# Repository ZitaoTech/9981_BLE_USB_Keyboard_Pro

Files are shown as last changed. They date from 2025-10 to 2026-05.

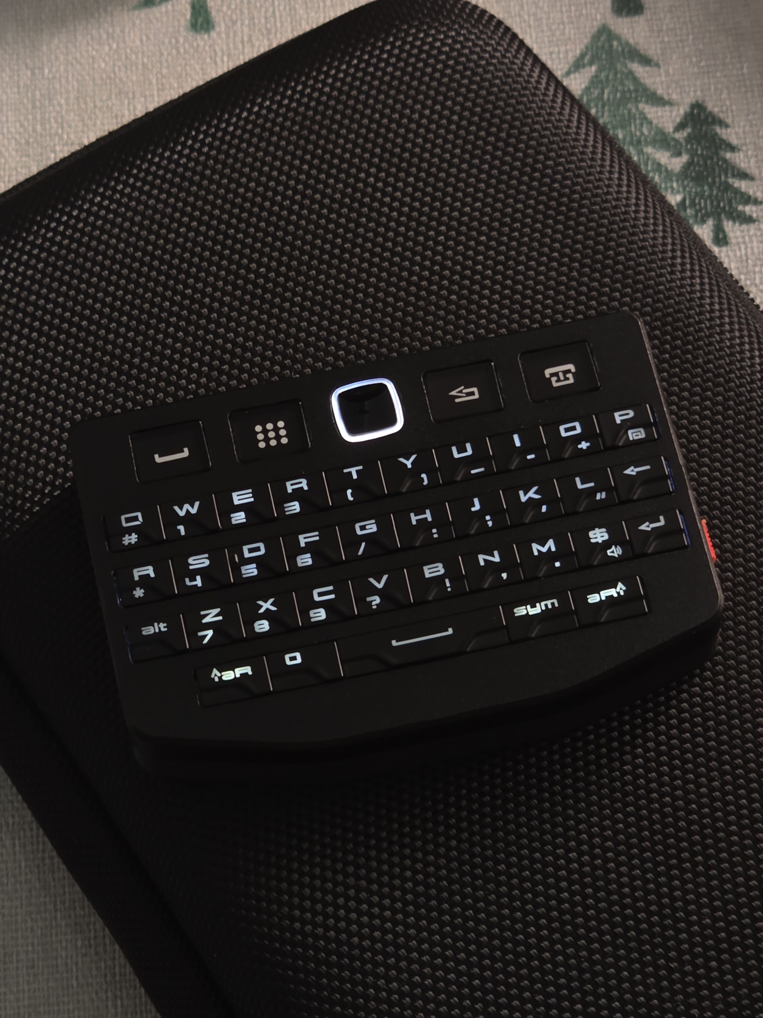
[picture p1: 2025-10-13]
Gallery/Foto2.jpg

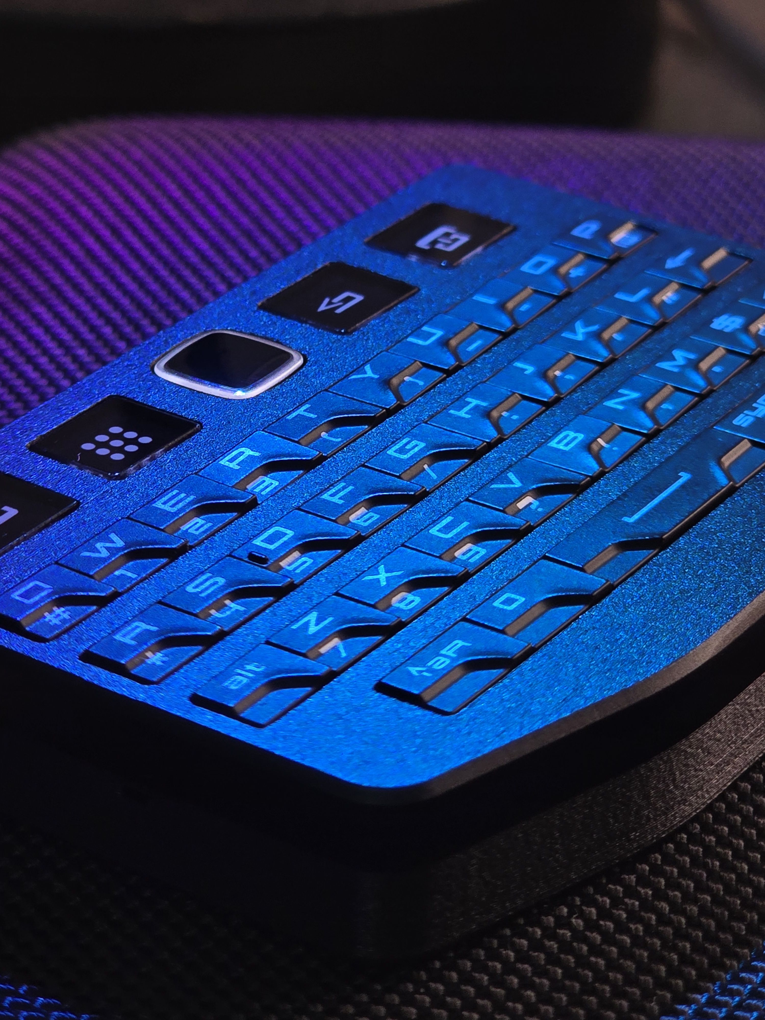
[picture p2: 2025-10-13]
Gallery/Foto5.jpg

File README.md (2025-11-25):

# P9981 BLE&USB Keyboard Pro ⌨️
The fully open-sourced P9981 BLE&USB Keyboard is the smallest ZMK-powered keyboard mouse combo and features n-Key rollover that other original blackberry keyboards don't have!

### [You might also be interested in P9981 Keyboard Air](https://github.com/ZitaoTech/9981_BLE_USB_Keyboard_Air/tree/main)
# Image Gallery

<table>
    <tr>
        <td></td>
        <td></td>
    </tr>

</table>

## Contents
- [About this keyboard](#about-this-keyboard-)
- [Before you buy/use](#before-you-buyuse-)
- [Where to buy](#where-to-buy-)
- [How to use this keyboard and keymap](#how-to-use-this-keyboard-)
- [How to connect this keyboard with your device](#how-to-connect-this-keyboard-with-your-device-)
- [Multi device connect](#multi-device-connect-)
- [Trackpad](#trackpad-)
- [USB&BLE Output select](#usbble-output-select-)
- [Keymap updating](#realtime-keymap-updating-)
- [Tipps for Android and iPhone users](#some-tipps-for-using-this-keyboard-)
- [Advanced methods of using this keyboard](#advanced-methods-of-using-this-keyboard-)
- [Troubleshoot](#troubleshoot-)
- [Dimension and weight](#dimensions-of-the-keyboard-)
- [Inspiration](#inspiration-)

# About this keyboard [🔼](#contents)
This mini Keyboard uses the cloned P9981 keycap with Blackberry 9380 trackpad and powered by the NRF52840 Microcontroller and operates under ZMK Firmware with extra custom driver.  

| Main Features |  | 
| :--- | :----: |
| Processor | [NRF52840](https://www.nordicsemi.com/products/nrf52840) from Nordic Semiconductor | 
| Firmware | ZMK firmware  | 
| Backlight | Keyboard with white backlight|
|Battery type| Integrated li-on battery|
|Battery capacity| 750mah with up to 3 months battery life(assume 1 hour per day)|
|Mouse and scroll wheel 2 in 1|When Capslock, the trackpad works as scroll wheel|
|USB&BLE Output|Support both wired and wireless connect|
|Shoulder keys|There are two shoulder keys on top|
|Small size| The smallest wireless keyboard mouse combo in the world|
|Aluminium body|The top case is made of aluminium, lower case 3d printed|
|Multidevice connect| The keyboard can be paired with up to 4 devices at the same time|
|Open source| [Hardware](https://github.com/ZitaoTech/9981_BLE_USB_Keyboard_Pro/tree/main/Hardware) and [software](https://github.com/ZitaoTech/9981_BLE_USB_Keyboard_Pro/tree/main/ZMK%20source%20code) all open sourced|
|__NKRO__|__There are integrated diodes on the keyboard, all the keys can be pressed at the same time__(Other original Blackberry keyboards don't have this feature)|

## Before you buy/use [🔼](#contents)

**Bluetooth version check**: This keyboard can only be paired wirelessly with devices that have **BLE 4.2 module or higher**, please check if your device have the right Bluetooth module, otherwise the keyboard can not work with your device wirelessly!  
How to check the Bluetooth version of your device: google (your device name) like iphone 8 and plus Bluetooth version and you will find the answer like this:
 BLE VERSION CHECK

## Where to buy [🔼](#contents)
- **If you are outside China**: You can buy the keyboard at [Elecrow](https://www.elecrow.com/p9981-ble-usb-keyboard-pro.html)    
- **If you are in China**: 在闲鱼搜索用户御坂200016号

# How to use this keyboard [🔼](#contents)
- By default the keyboard has 4 Layers, when you just turn on the keyboard, the keyboard is at layer0-the QWERTY layer.  
- When you tap or hold the ```SYM``` key, the keyboard will enter layer1, and the keyboard backlight will start blinking, you can type numbers or symbols at this layer.  
- When you tap or hold the ```aA``` key at the lower right corner, the keyboard will enter layer2 and the keyboard backlight will do a loop effect, you can type some symbols and do some Bluetooth behaviors at this layer.
- The layer 3 basically has no keycode, this layer is reserved for the customer, and the keyboard backlight will blink the twice speed as the layer 1 when you are at layer 3.  

**Now let's check the keymap.**  
## Keymap [🔼](#contents)
**Layer0-QWERTY**    
<p align="center">
  9981_PRO_layer0
</p>

> [!NOTE]
> - **What means sticky ctrl?** If you want to copy something, you can tap Ctrl and then tap C, the keyboard will triger Ctrl+C, you can do that with one hand.  
> - **What means sticky layer?** A sticky layer stays pressed until another key is pressed. Example: when you short type sym key, the keyboard will enter sticky layer1 after you type the "B" key, the keyboard will type "!" and return to layer0, it's easier to type with one hand.  
> - **What means lock layer?** The "lock layer" behavior enables a layer while a certain key is pressed. Example: when you want to type many numbers you can hold the sym key and tap "WER" and the keyboard will type "123", when you release the sym key, the keyboard will return to layer 0.  
> - **What means to layer?** By default when you double tap the dollar key, the keyboard will go to layer 1, then you can type numbers without pressing the sym key, you need to manually return to layer0 by tap the sym key at layer1.  

**Layer1-Numbers and symbols**    
<p align="center">
9981_PRO_layer1 
</p>
 
**Layer2-Functional keys**   
<p align="center">
9981_PRO_layer2  
</p>

> [!NOTE]
> - **What does Eject key do?** When you press E at layer 2, the keyboard will type Eject, Eject can ```bring up``` or ```disable``` keyboard on screen on iphone, this key is important because on iphone by default the keyboard on screen is disable when iphone is connected withe external keyboard.
> - Double tap the trackpad on this layer which trigger the ```Clear bluetooth pairing``` is very important to pair with another device more info please check the content [How to connect this keyboard with your device](How-to-connect-this-keyboard-with-your-device-)
> - This Layer contains many important keycode about Bluetooth connect and Multiconnect, more info please check

**Layer3-Reserved layer for extra keys**   
<p align="center">
9981_PRO_layer3 
</p>

> [!NOTE]
> - You enter Layer 3 by double tap dollar key at layer 1, you can customize how to enter this layer yourself by editting the keymap.  
> - You can set some key at this layer as Media key like ```next song``` or ```pause``` which I think should be useful.

## How to connect this keyboard with your device [🔼](#contents)
- Turn on the Bluetooth on your phone
- Find the device ```bbp9981``` and pair with it then you should type with the keyboard
- There are some settings for IOS users, please check [this](https://github.com/ZitaoTech/9981_BLE_USB_Keyboard_Pro/tree/main?tab=readme-ov-file#iphone-or-ios-users-).
> [!CAUTION]
> After you delete the bluetooth profile and if you want to pair with the keyboard with another device when you have already paired with some device before, make sure to enter layer 2 and double tap the trackpad to clear the bluetooth profile on the keyboard side. Otherwise there will be error when you want to pair with another device!!! Please use the following steps to delete the bluetooth pairing
- First delete the bluetooth profile(somewhere it's called forget the device or unpair the device) on your device
- Enter layer 2 and doubletap the trackpad(You can tap the lower right aA key to trigger sticky layer 2 or hold the aA key to enter layer2)
- Refresh the Bluetooth setting page on your device(You can turn on and off the bluetooth) and then you can pair with the keyboard again

## Multi device connect [🔼](#contents)
By default the keyboard can be paired with 4 devices at the same time and can be switched between them seamlessly. Here are the steps how to connect with devices:
1. Assume you have already connected this keyboard with one device
2. Now enter layer 2 and press the second bigger top row key
<p align="center">

</p>
Now the keyboard is ready to be paired with second device.  
Similarly, you can pair this keyboard with a third and a fourth device.  

3. Once pairing is done, you can switch between the devices the same way.

> [!CAUTION]
> - The BT_CLEAR keycoode — which is triggered by double-tapping the trackpad on Layer 2 — is calculated independently for each device. This means that when you trigger BT_CLEAR while connected to the second device, it won’t affect any of the other devices.

## Trackpad [🔼](#contents)
- There is a trackpad which can be used as mouse, iPhone users need to enable the AssistiveTouch function to use the trackpad as mouse.  
- Trackpad led: When you put your finger on the trackpad, the trackpad led will light up and the brightness will show the speed of the mouse speed(the higher the dpi, the more brighter the led) When the keyboard is waiting to be paired or the output is USB, the trackpad led will start blinking.  
- How to adjust the mouse speed: Enter layer 2 and press V to decrease the dpi, or press N to increase the dpi. The dpi can be shown by the brightness of the trackpad led.
- Scroll function: When Caps Lock is activated, the trackpad led enters a cyclic lighting mode, and the trackpad works as a scroll wheel.

## USB&BLE Output select [🔼](#contents)
The keyboard supports both USB and BLE output, by default the output is BLE. Assume the keyboard is both connected with a PC and paired with a phone, you can toggle the output by double-tapping the dollar key at layer2, if the output is USB the trackpad led will start blinking every second.

## Realtime Keymap Updating [🔼](#contents)
[ZMK Studio](https://zmk.dev/docs/features/studio) provides runtime update functionality to ZMK powered devices, allowing users to change their keymap layers without flashing new firmware to their keyboards.  

You can use ZMK Studio with ```Chrome/Edge``` at [https://zmk.studio/](https://zmk.studio/).  

Before you use ZMK Studio, you need to ```turn off``` the bluetooth from your phone that the keyboard is paired with, then you can select the port shown on the ZMK Studio page and then start the keymap updating.  

The picture below shows you how it looks like when the keyboard connects with ZMK Studio successfully.

<p align="center">

</p>

> [!NOTE]
> Currently The ZMK Studio is still beta version, there are some functions that ```can not``` be configured e.g. macro, 
> there is another advanced way to update the keymap, please check the content below

## Advanced Keymap Updating [🔼](#contents)
Since the ZMK Studio is still in beta stage, There’s also a more straightforward method to edit the keymap.  
Please refer to this [page](https://github.com/ZitaoTech/zmk-config-9981-pro)

## How to update the firmware [🔼](#contents)
Because this keyboard is powered by open sourced ZMK firmware, which allows you to modify different features yourself, and thus you might need to update the firmware yourself. The following are steps to update the firmware.

1. Connect the keyboard with a computer
2. Make the keyboard into bootloader mode(By default you need to enter layer2 and press the dollar key)
3. A new USB Disk will be found by you computer
4. Drag the new .uf2 firmware file into the USB Disk and the keyboard is finished with updating

## Emergency way to enter bootloader [🔼](#contents)
There is a hole at the bottom of the keyboard, and inside that's the reset button. After connect the keyboard with a computer, you can quickly tap the reset button using a small pin to force the keyboard into ```bootloader mode```

<p align="center">

</p>

# Some tipps for using this keyboard [🔼](#contents)
## iPhone or IOS users [🔼](#contents)
If you need to use trackpad as mouse or scroll wheel function on iphone or ipad, there are some settings that you need to do:

- Go to Settings-> Accessibility-> Touch-> AssistiveTouch -> enable AssistiveTouch and you can use touchpad as mouse on iphone or ipad
- Go to Settings-> General-> Keyboard-> Hardware Keyboard-> disable Cpas Lock Language Switch and you can use the trackpad as scroll wheel when capslock is on.

And you can disable the always show menu to remove the grey dot when your phone is connected with keyboard
<p align="center">

</p>

## Android users [🔼](#contents)
I noticed that about ten seconds after the keyboard is paired with an Android phone for the first time, it will reconnect once. During this brief period, you won’t be able to type or move the mouse. This is normal, so don’t worry.

Shortcuts: 
**There are some useful shortcuts on android phones:**
- Hold gui key and press N to check messages.
- Hold gui key and press enter to go to desktop.
- Hold alt and press tab to enter multiapp control.

**What's the ```gui key```?**
<p align="center">

</p>
By default that's the second bigger top row key, it's also the command key(⌘) on IOS

# Advanced methods of using this keyboard [🔼](#contents) 

## Build your own firmware [🔼](#contents)
First you need to build the toolchain of ZMK firmware, it's recommended to build it under Github Codespaces. Here are the steps for you to build the toolchain via Codespaces:  
0. Register a Github account if you don't have one
1. Access the zmk firmware [github page](https://github.com/zmkfirmware/zmk)  
2. Create a codespace by clicking this icon:

<p align="center">

 </p>
 
3. When the codespace is finished setting up, type ```cd zmk ``` in the terminal of the codespace
4. type ```west init -l app/``` in the terminal
5. type ```west update``` and wait about 5-10 minutes and the toolchain is finished setting up
6. copy and paste the ```bbp9981``` [folder](https://github.com/ZitaoTech/9981_BLE_USB_Keyboard_Pro/tree/main/ZMK%20source%20code/bbp9981) into the ```app/boards/arm``` folder
7. compile the firmware by using ```cd app``` and ```west build -p -b bbp9981``` and zmk will start compiling the firmware
8. the compiled firmware is ```app/build/zephyr/zmk.uf2```. You can download and update the firmware
# Troubleshoot [🔼](#contents)
- Why did the keyboard feel bad to type on when I first receive it?

Because the keycap is made of silicone, when the keyboard is transported by air, the low temperature can make the silicone stiffen slightly. So when you first receive the keyboard, it may feel bad to type with. Once it warms up to room temperature, the typing feel will improve. The same thing also happens with other BlackBerry keyboards.  
- Why is my trackpad not moving?

The trackpad can be manually turned on/off. You may have accidentally pressed ‘T’ on Layer 2 and disabled it. In this case, enter Layer 2 again and press ‘T’ once more to re-enable the touchpad.  

There is another possibility: the trackpad itself might be defect. Here is a quick way to verify it:  

First, place your finger on the touchpad and move. See whether the trackpad backlight lights up.
If not, enter Layer 2 and press ‘T’. Then place your finger on the trackpad again and move.
If the trackpad backlight still does not light up, the touchpad is likely defective.
In this case, please contact Elecrow.  

- Why can't my keyboard be paired with my device?

It’s possible that after the previous pairing, the keyboard didn’t clear its pairing information. You need to switch to Layer 2 and double-tap the touchpad to erase the keyboard’s pairing data, and then you can start a new pairing.

> [!CAUTION]
> After deleting the pairing on your phone or on the keyboard, it’s important to refresh the Bluetooth page on your device. The easiest way is to just restart Bluetooth module.

If in this way your device still can't pair with the keyboard, please follow the steps below:  

Press and hold the **aA** key at the bottom-right corner, then press the **first top-row key**, and double-tap the touchpad.  

Next, without releasing the aA key, press the **second top-row key**, and double-tap the touchpad again.
Repeat this process for **all four top-row keys** to clear pairing information for all 4 bluetooth channels.  

After that, pair your device with the keyboard again.

- Why is my keyboard not having backlight?

Enter layer 2 and press ‘B’ so you can bring the backlight back again

# Others [🔼](#contents) 
## Dimensions of the keyboard [🔼](#contents)
The picture below shows the outerline dimension of the keyboard  
9981_PRO_dimension
## Weight [🔼](#contents)
The total weight of the keyboard is 53.3 g

# Inspiration [🔼](#contents) 
This [page](https://github.com/ZitaoTech/9981_BLE_USB_Keyboard_Pro/tree/main/Inspiration) shows what the keyboard can do besides functioning as a standalone Bluetooth keyboard.

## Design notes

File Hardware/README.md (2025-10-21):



There are two custom PCBs inside the keyboard:  
1. Dome sheet PCB with 1.6mm thickness  
2. Main PCB with 1.0mm thickness  

These two PCBs are connected via two 16-pin board-to-board connectors

Dome sheet PCB:  
3fd71eb90a61267e5f55e46590c34631
There will be a custom ordered dome sheet attached on the PCB  
5c5008502b5ae1ba0b157d0c470c3f69
Foto of the two PCBS:  
0297fbe53108b78d6377a41427420c7a

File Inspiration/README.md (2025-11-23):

# Inspiration
This page shows what the keyboard can do besides functioning as a standalone Bluetooth keyboard.

- ### Connect with a phone with magnet system
<div style="display: flex; gap: 10px;">
  
  
</div>

- ### Mini cyberdeck
<p align="center">

</p>

- ### Custom enclosure
<p align="center">

</p>

- ### Phone case for Samsung Z Flip 5 or 6
<p align="center">

</p>

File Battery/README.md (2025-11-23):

# Battery inside the 9981 BLE&USB keyboard

The battery used on 9981 pro keyboard is ```503048``` 750mah Lithium-ion battery.

All certifications and documents related to this battery are in the folder on this page

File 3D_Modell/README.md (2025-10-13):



Screws needed to assemble 9981 BLE&USB keyboard pro:  

4 pcs ```M2x10``` hexagon socket countersunk head screws  
2 pcs ```M2x4``` flat head countersunk head screws

### Parameter about the 3d printed part:

Print maschine: Bambu Lab A1 mini    
```Red switch:``` Nozzel size:0.2mm  
```Top Row key support:``` Nozzel size:0.2mm  
```Lower case:``` Nozzel size:0.4mm

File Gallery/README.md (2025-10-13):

Foto1
Foto2
Foto3
Foto4
Foto5
Foto6
Foto7

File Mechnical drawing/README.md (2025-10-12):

9981_PRO_dimension

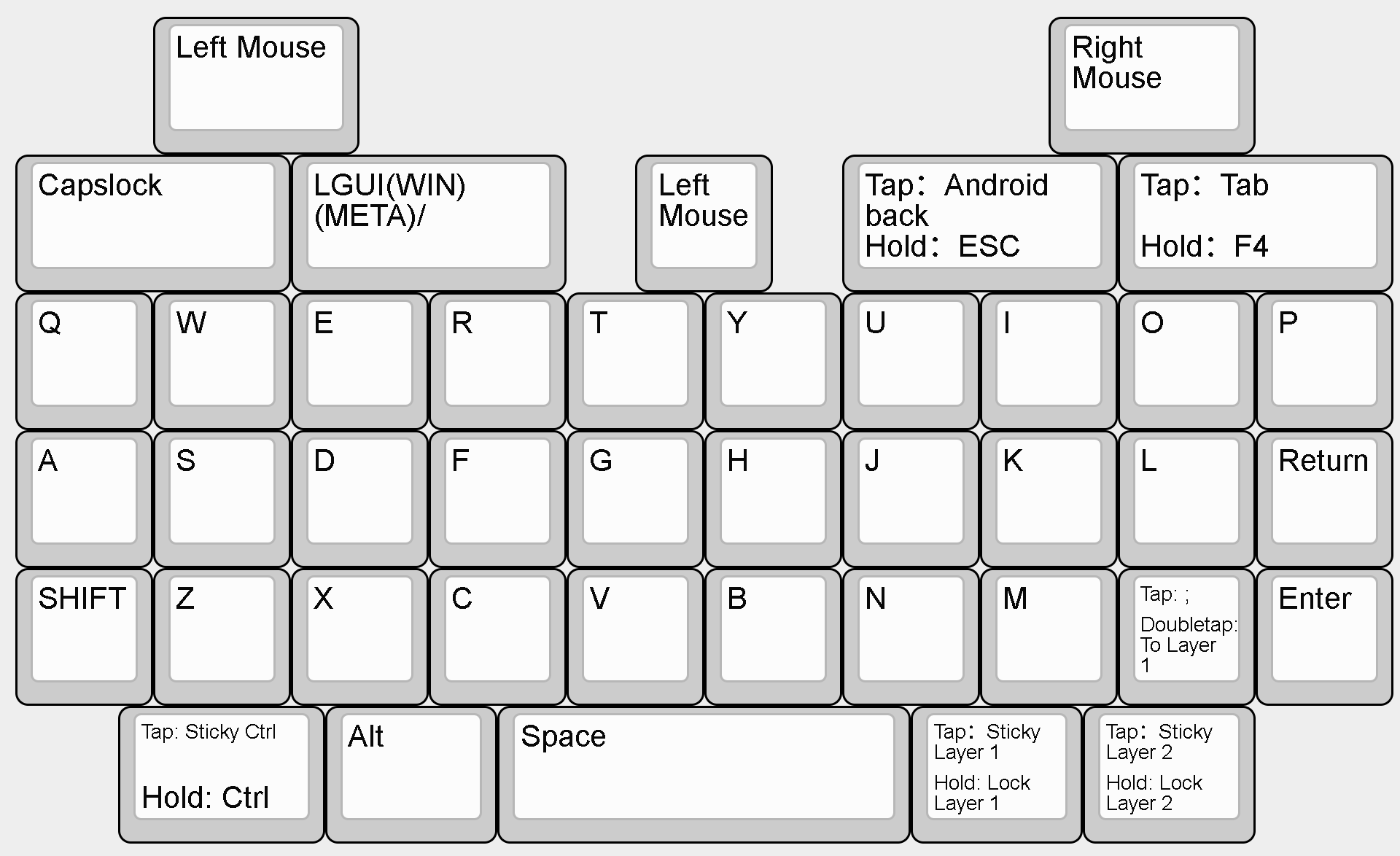
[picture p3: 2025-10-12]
Pic/9981_PRO_layer0.png

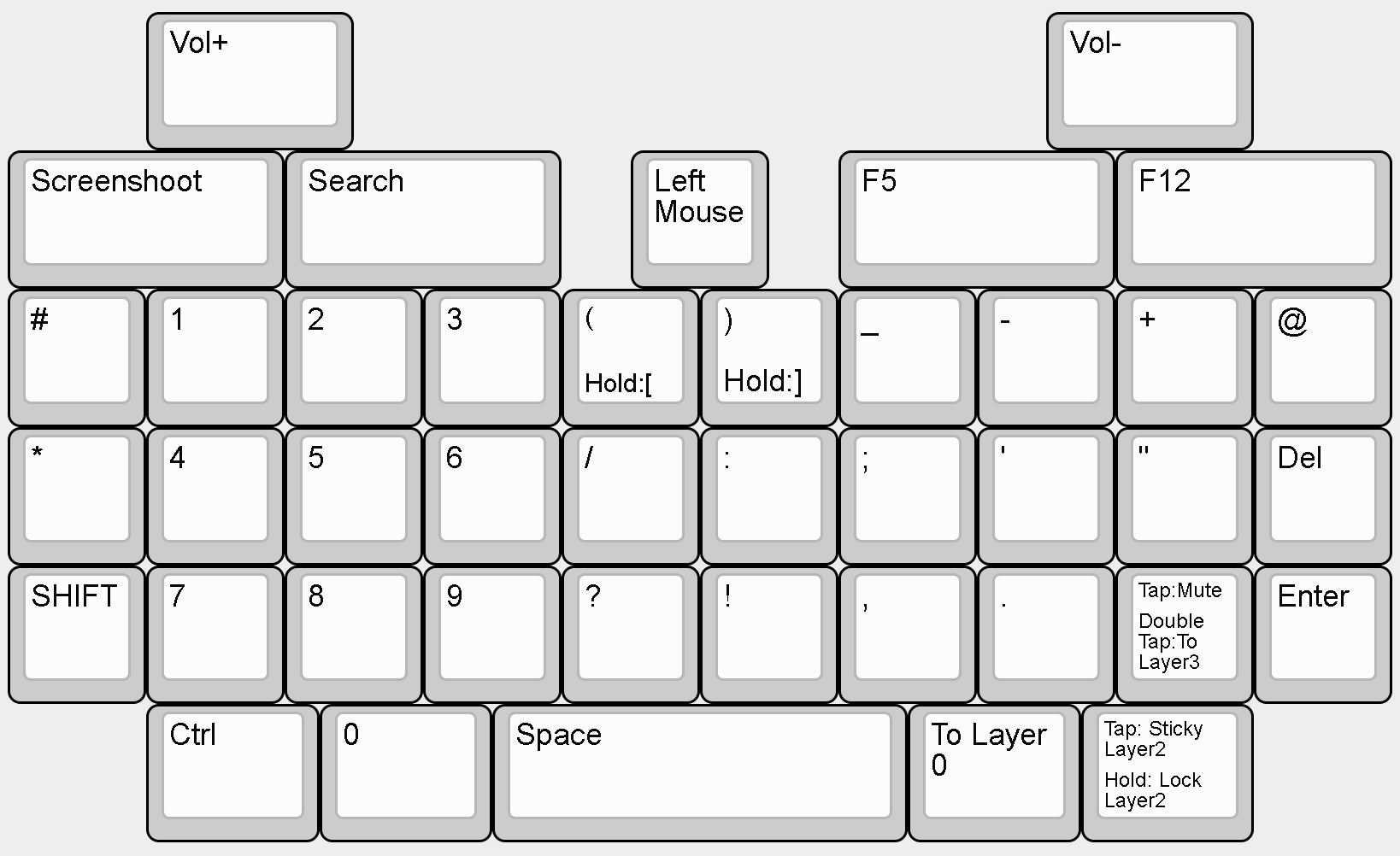
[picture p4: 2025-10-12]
Pic/9981_PRO_layer1.png

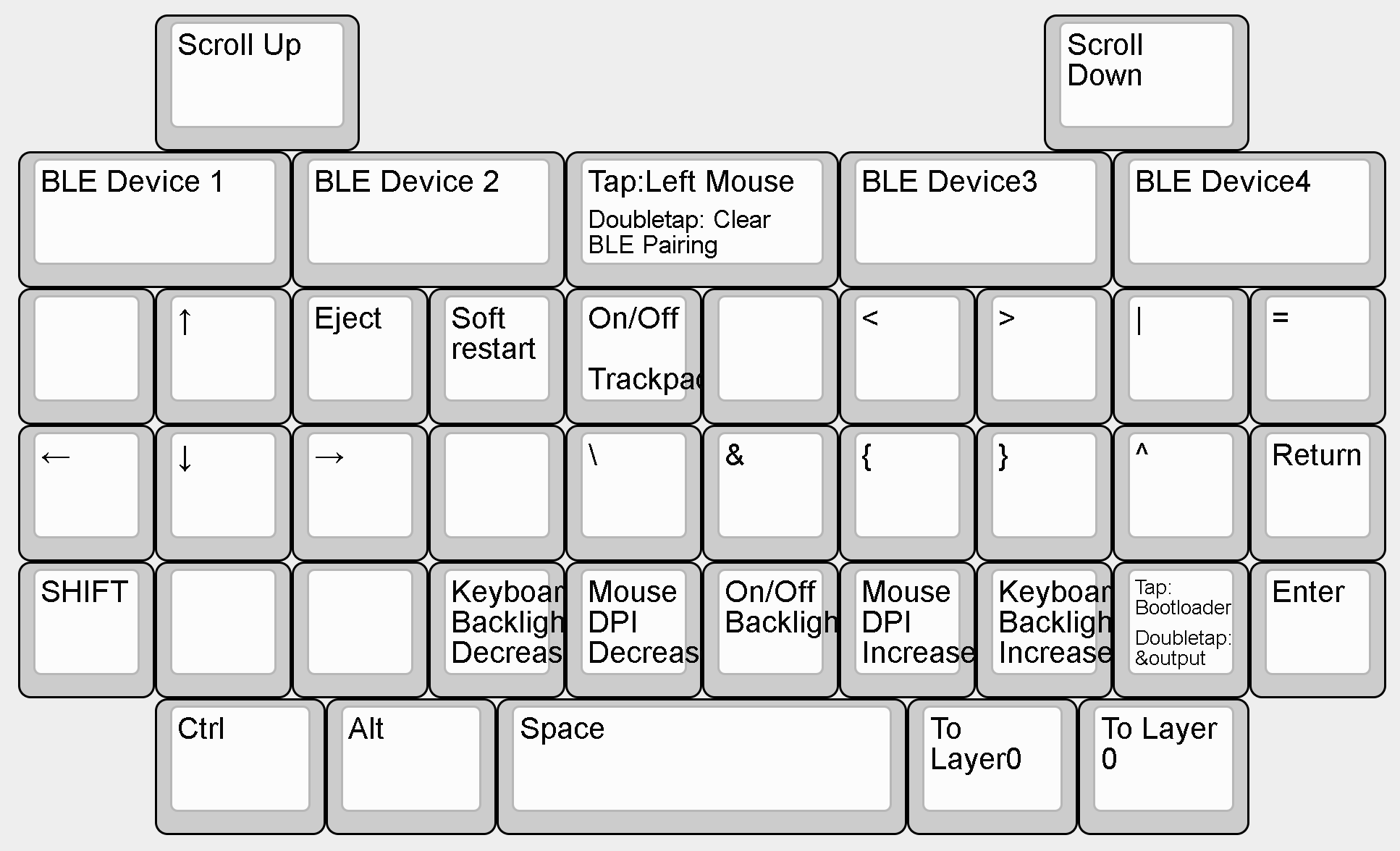
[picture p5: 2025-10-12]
Pic/9981_PRO_layer2.png

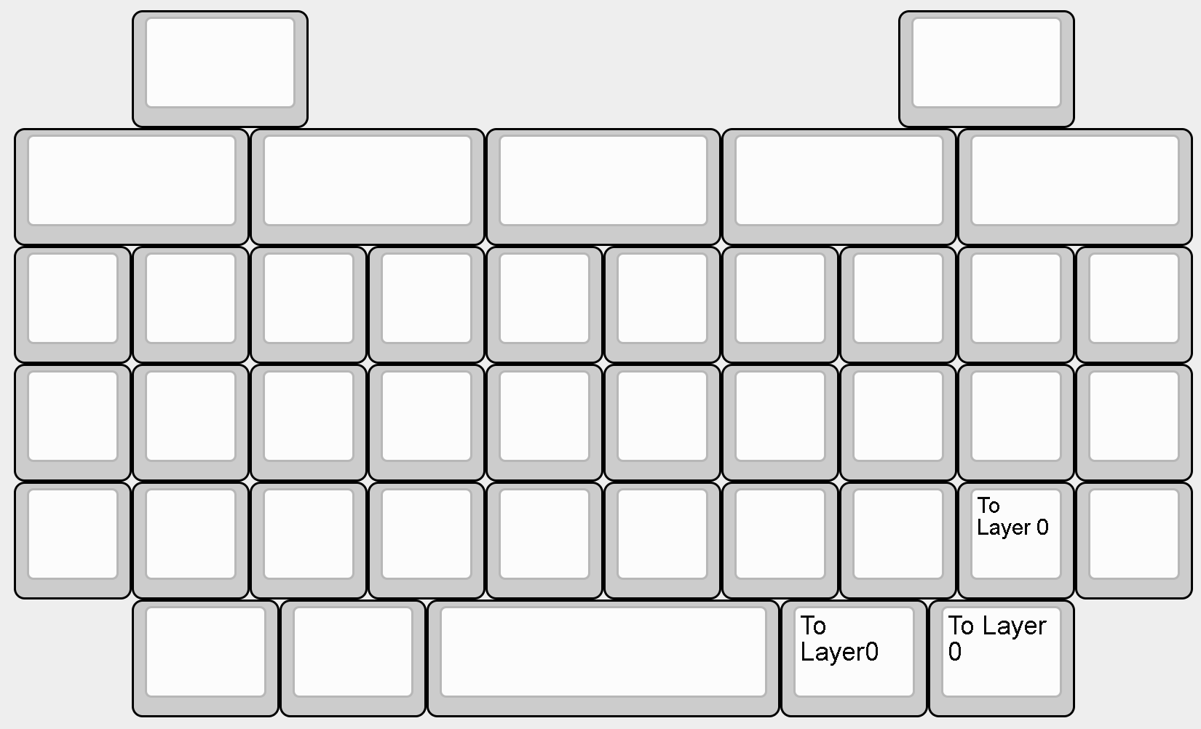
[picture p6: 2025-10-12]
Pic/9981_PRO_layer3.png

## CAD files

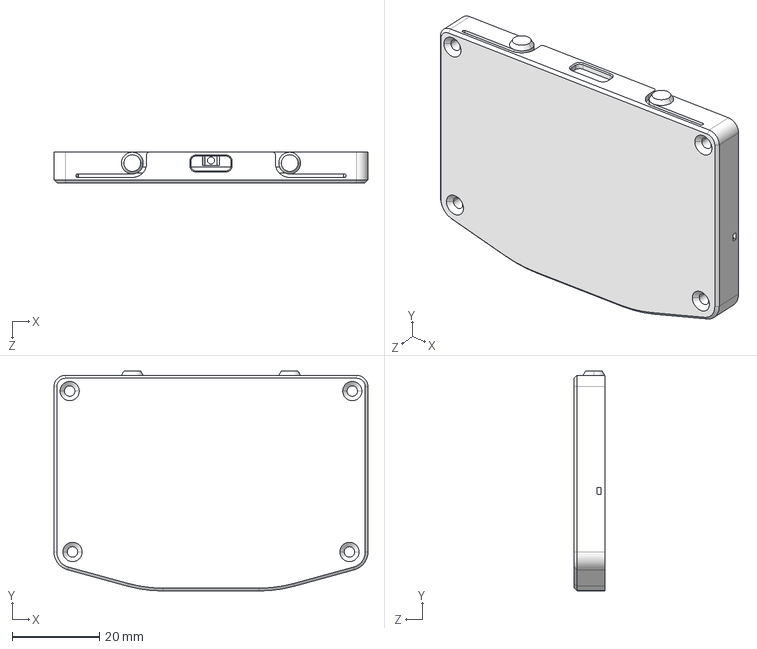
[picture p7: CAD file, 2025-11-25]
3D_Modell/9981_PRO_bottom_case.STEP
71.9 x 50.3 x 7.00 mm

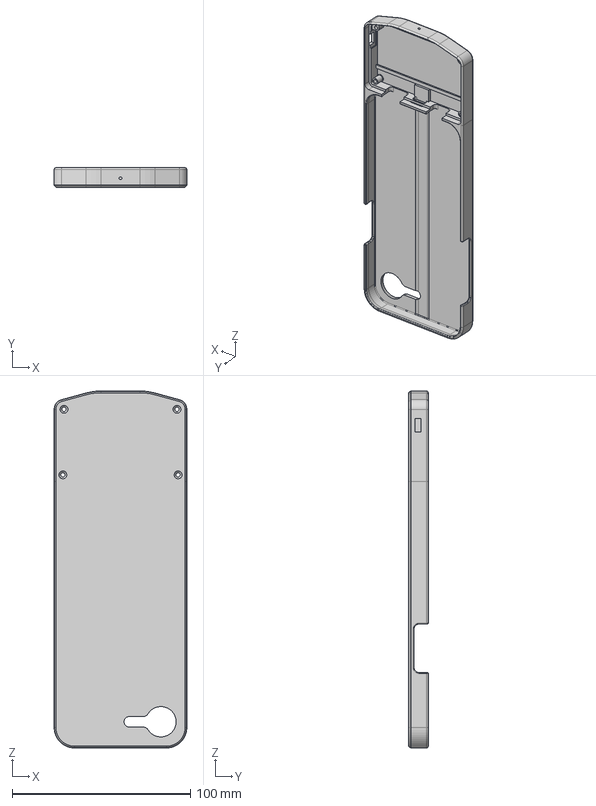
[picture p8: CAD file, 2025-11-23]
Make a keyboard case for your phone/iphone16E-9981-pro-keyboard-case.step
74.5 x 11.0 x 200.4 mm

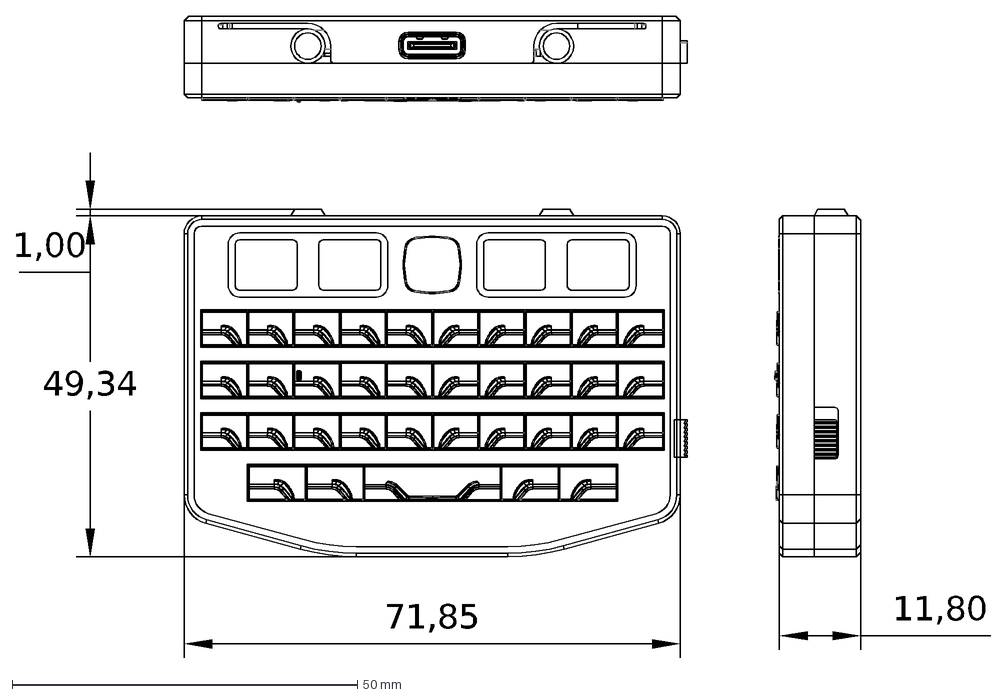
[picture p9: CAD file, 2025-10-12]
Mechnical drawing/9981_pro.dxf
71,85
49,34
1,00
11,80

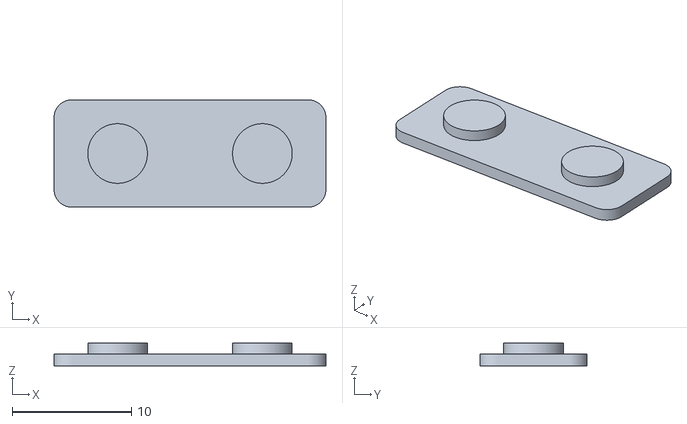
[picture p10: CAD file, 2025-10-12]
3D_Modell/9981_PRO_Toprow_keys_support.stl
22.8 x 9.00 x 1.90

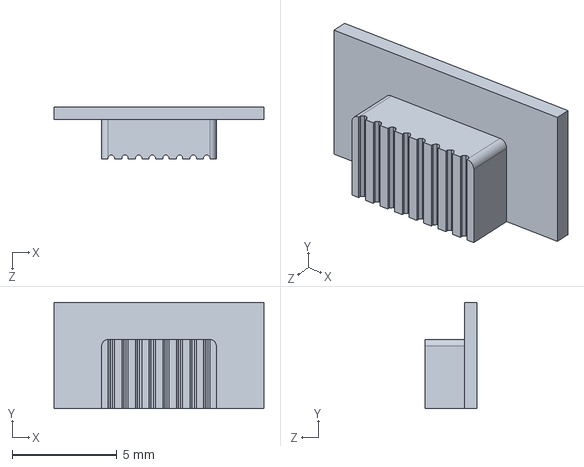
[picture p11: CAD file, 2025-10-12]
3D_Modell/9981_Red_power_switch.STEP
10.0 x 5.05 x 2.49 mm

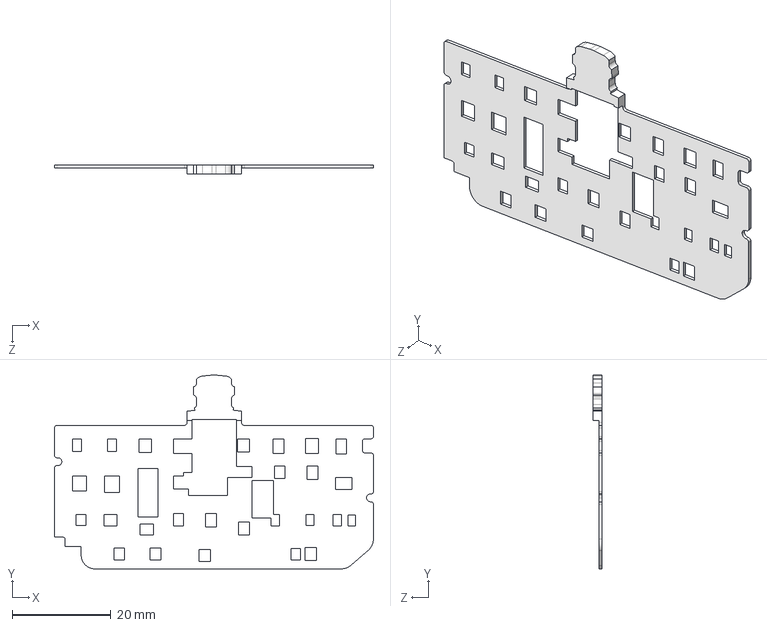
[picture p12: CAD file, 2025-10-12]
3D_Modell/9981_PRO_under_keyboard_support.STEP
64.5 x 39.2 x 1.75 mm

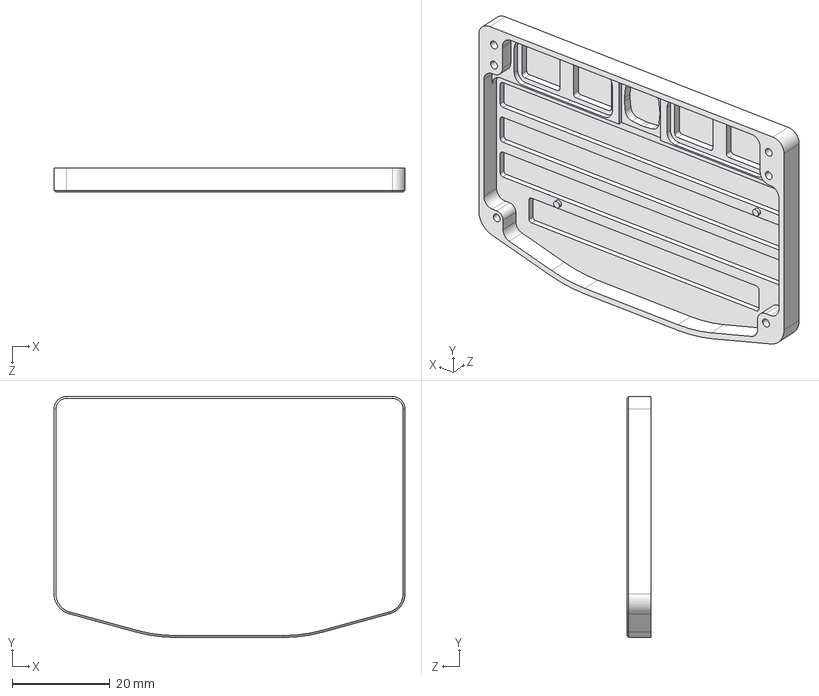
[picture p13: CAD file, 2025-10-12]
3D_Modell/9981_PRO_top_case.STEP
71.9 x 49.3 x 5.00 mm

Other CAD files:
Mechnical drawing/9981_pro.DWG

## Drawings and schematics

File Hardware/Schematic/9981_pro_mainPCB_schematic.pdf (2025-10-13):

# USB

# NRF52840

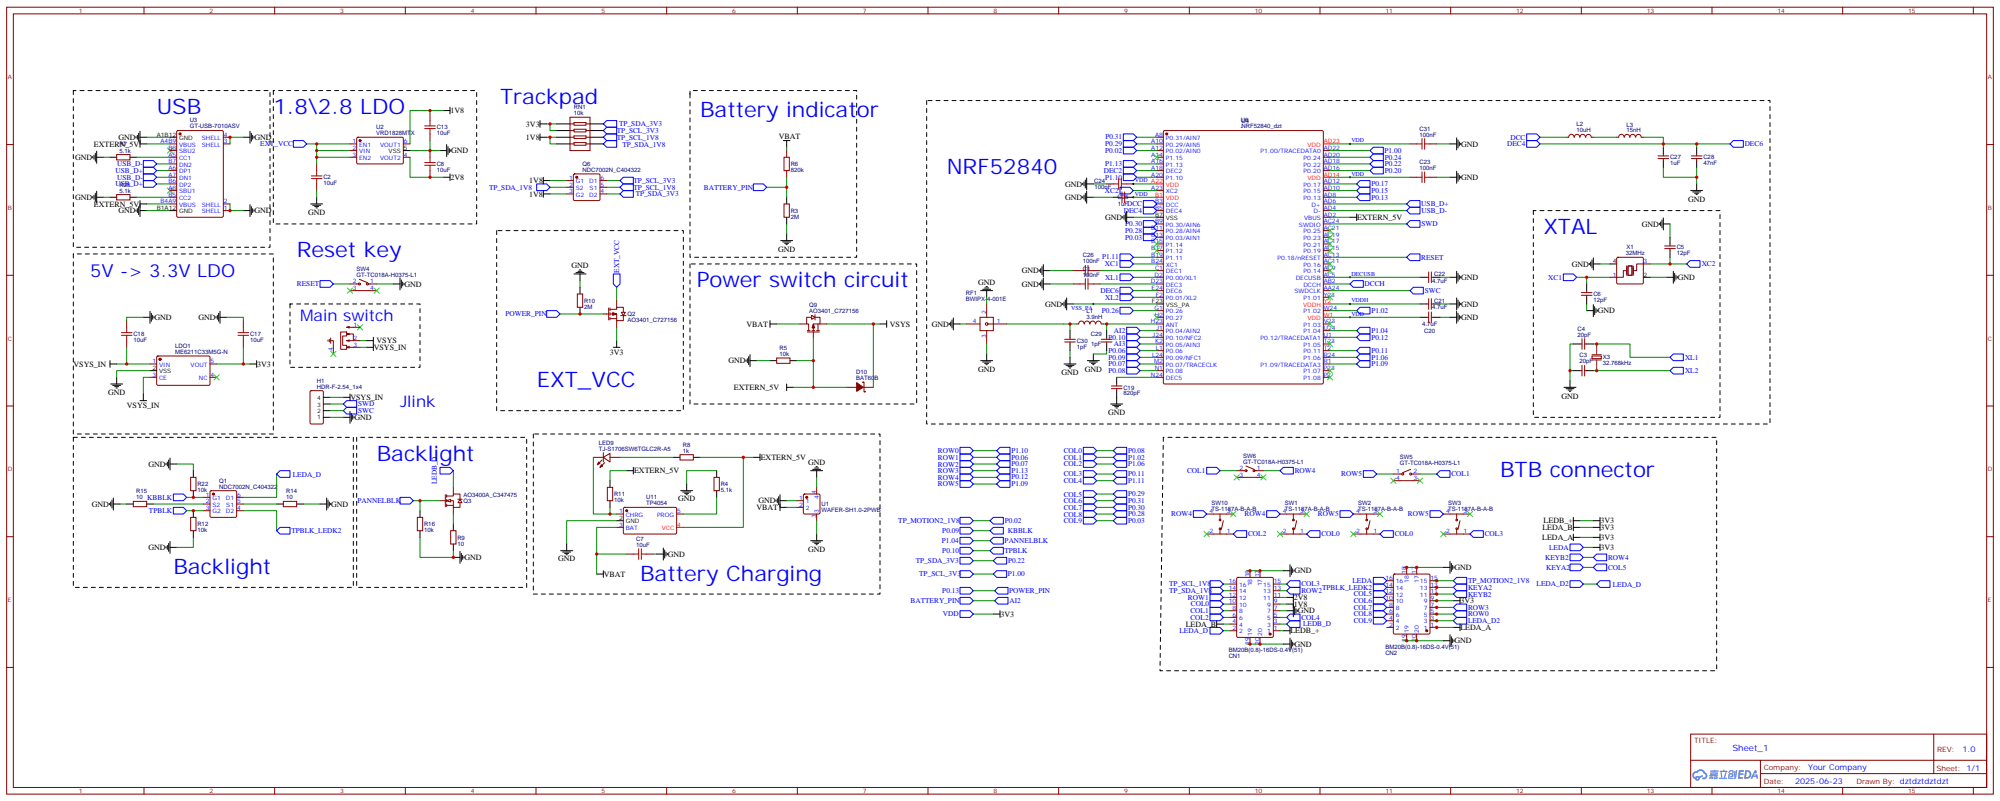
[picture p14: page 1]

SHELL 1 GND B1A12 VBUS B4A9 CC2 B5 SBU1 A8 DP2 B6 DN1 A7 DP1 A6 DN2 B7 CC1 A5 SBU2 B8 VBUS A4B9 GND A1B12

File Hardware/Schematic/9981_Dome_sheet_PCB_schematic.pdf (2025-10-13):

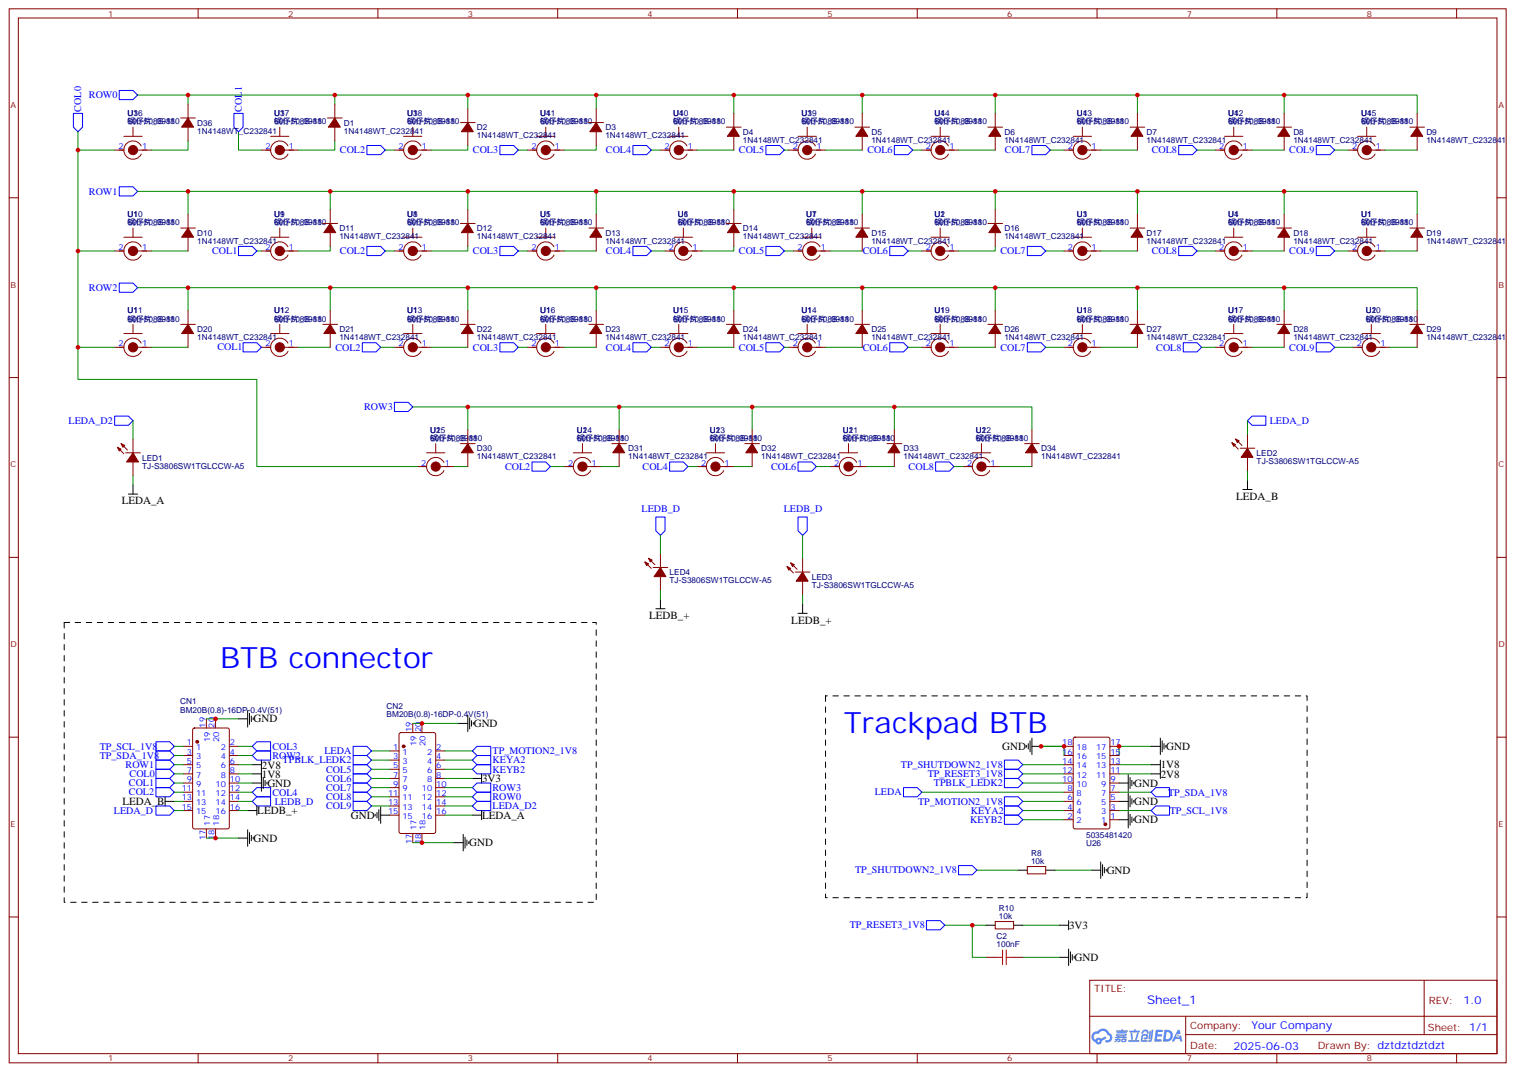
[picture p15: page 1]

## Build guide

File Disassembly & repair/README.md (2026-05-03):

# Disassembly & Repair

This page will show you how to disassemble the 9981 Pro keyboard for repair and modification

### So we have the keyboard right now

<p align="center">

</p>

### Then we flip the keyboard over and remove these four screws.

<p align="center">

</p>

### When removing the back cover, pay attention to the antenna attached to it. Carefully detach the antenna from the cover, and make sure not to pull or break it.
<p align="center">

</p>

### Now we can see the main board. Remove these two screws to separate the motherboard from the top case.
<p align="center">


</p>

### After separating the top case, we can directly remove the 9981 keycaps from the smaller dome sheet board.
<p align="center">


</p>

### Then we can use our fingernail to pry off the dome sheet board.
<p align="center">

</p>

### Now we have fully disassembled the 9981 Pro keyboard.
<p align="center">

</p>

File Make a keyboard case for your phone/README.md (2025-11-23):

# Make a keyboard case for your phone

This page will tell you how to make a phone case with keyboard for your phone.

> [!NOTE]
> - You’d better have your own 3D printer, preferably from Bambu Lab. 

Since the width of 9981 pro keyboard is 71.85mm. You should choose a phone with almost the same width. Now let's take iPhone 16E as an example, which has 71.5mm width.

The picture shows the 9981 keyboard case made for iPhone 16E

<p align="center">

</p>

### When designing this keyboard case, keep the following points in mind:

- **Remember to leave some room for the shoulder keys**
<p align="center">

</p>

- **Thickness of the case should be not smaller than 1.5mm**
<p align="center">

</p>

- **It's recommended to use PETG filament**

### And the final product looks like this.
<p align="center">

</p>
